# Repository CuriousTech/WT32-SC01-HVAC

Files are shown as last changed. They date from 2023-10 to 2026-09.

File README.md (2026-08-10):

# WT32-SC01-HVAC  

Thermostat vid  
  
WiFi Smart Omniscient Opensource Arduino ESP32 HVAC Touchscreen Thermostat using WT32-SC01 (not PLUS)  OSHPark [Rev1](https://oshpark.com/shared_projects/ljZTJh9A) $15.65  [Rev2](https://oshpark.com/shared_projects/giHlVB41)  

This code is currently too large for ESP-IDF 3.x.x but may be optimized further at some point. Another option is to replace the ESP32-WROVER-B module with the newer WROVER-E-N8R8 or N16R8, which increases the code space by 2x or even 4x.
  
This is the 3rd thermostat I've designed, only because new hardware makes it better, and tends to remove some limitations.  
All sensors from [ESP-HVAC](https://github.com/CuriousTech/ESP-HVAC), and older models can be used as remote units by building as REMOTE. This model can be changed to remote with just a temp/humidity sensor on the i2c pins, plus speaker if desired, and use the USB for power.  
  
This first version just emulated the Nextion HMI and kept all the code the same, except for Display.cpp/h, removal of any ESP8266 specific code, and the addition of an I/O pin to power the H/T sensor for reset purposes since it shares the i2c with the touch interface.  
Encoder.cpp/h was removed, but can be added back easily, with 4 extra I/O pins for expansion (IO36 is input only).  

The WT32-SC01 can be purchased from many vendors. It stays fairly cool, but the LM1117 is a bit inefficient, with a quiescent current of 5mA. These 2 linear regulators can be replaced with something better such as the AP2111H-3.3TRG1 to run it cooler. Soldering iron may be safer than a hot air gun unless the display is pulled away from the PCB (easy).  
  
To program: Copy the User_Setup/Setup201_WT32_SC01.h over the original. Some parameters were incorrect.  
Uncomment #include "Setup201_WT32_SC01.h" and comment the default in TFT_eSPI/User_Setup_Select.h  
Flash over USB first, and upload the SPIFFS data using ESP32 Sketch Data Uploader.  
If any libraries are missing, the error should be on the line with a link to the library. Some are in my ESP-HVAC repo.  
  
Some lines in code to change:  
&nbsp;&nbsp;&nbsp;&nbsp; Thermostat.ino: Uncomment the temp sensor used.  
&nbsp;&nbsp;&nbsp;&nbsp; HVAC.h: Uncomment #define REMOTE to compile for remote units. RMT1 should be changed to a uniique ID for each remote.  
&nbsp;&nbsp;&nbsp;&nbsp; WebHandler.cpp: ipFcServer(192,168,31,100); is the local forecast server IP. This is a comma delimited file for the current temps on a local server.  
&nbsp;&nbsp;&nbsp;&nbsp; eeMem.h: This has the SSID/password (or use EspTouch to set up), web access password, and OpenWeatherMap city ID, and many other default EEPROM values.  
&nbsp;&nbsp;&nbsp;&nbsp; OpenWeaetherMap.h: #define APPID "app id" is the long string from OpenWeatherMap.  
  
First test of the board came out almost perfect. The via close to the rectangle speaker can touch metal on the speaker and short. Use capton tape. It can go on the bottom or top. Bottom is better. The right capacitor doesn't clear the ESP32, even at 7mm tall. It only needs about 100uF at 25V, but more is better. They can be mounted to the back with the current case design.  
  
Thermal issues have been a struggle with this design, and the SHT40 is horrible sharing the i2c bus with the touchscreen. The AM2322 or AM2320 is a much better option. To reduce current, which effectively reduces heat, several changes were made: Setting clock to 80MHz instead of the default 240MHz, disabling the bluetooth radio, and lowering the LED backlight brightness (100 of 255) drops it from ~250mA to 150mA at 5V. Reducing the brightness further to 50 brings it down to ~80mA. At this point it produces very little heat, and is still almost bright enough for indoor visibility. 100 is really preferable.  
  
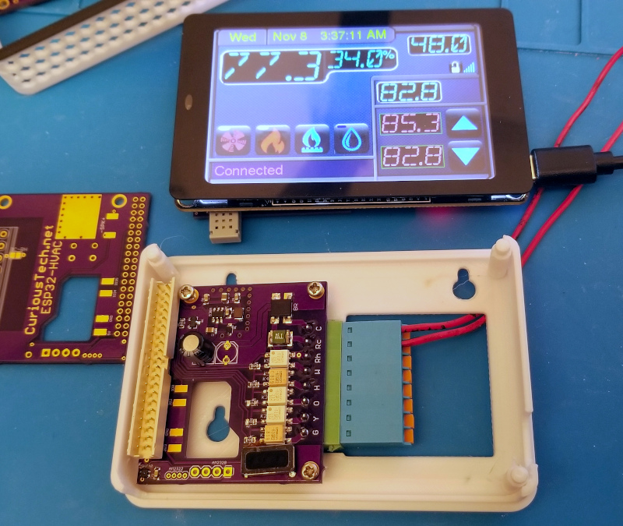
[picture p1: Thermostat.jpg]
Thermostat
  

With the printed case. I added about 5 inches of black before the white to match the display face (just stuck in front, not fused).  
  
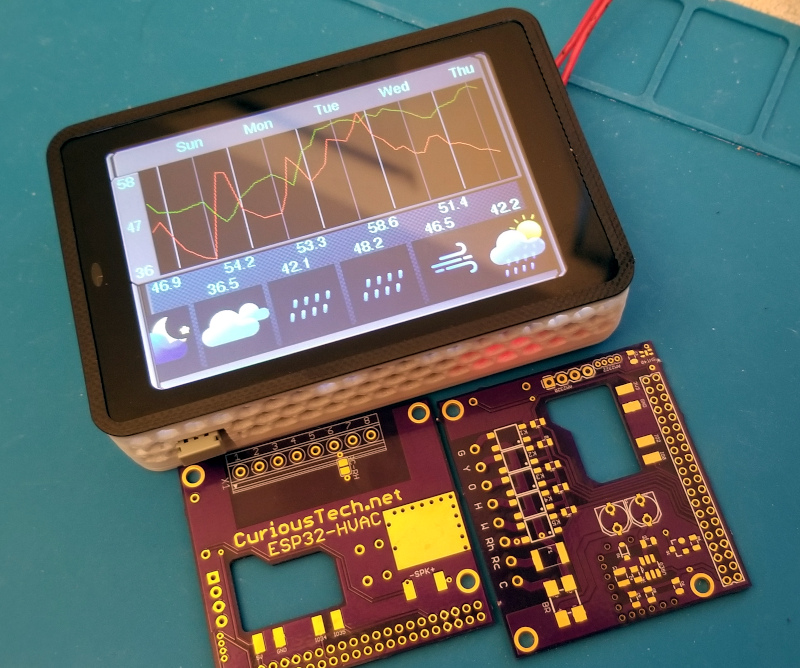
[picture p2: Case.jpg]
Case
  
  
HVAC wiring labels:  
 C (blue) common 24VAC  
 Rc (red or orange) 24VAC power for cool  (C and Rc power the thermostat)  
 Rh (red) 24VAC power for heat. Solder the Rc-Rh jumper on the back if not used.  
 Y (yellow) cool signal  
 O (color varies) compressor reverse for heatpump  
 W (white) heat signal  
 G (green) fan signal. Note: Heat and cool override manual fan signal.  
 H humidifier  
  
Main page:  

Cool/heat low/high:  
These are the desired temperature ranges for cooling and heating, which are calculated based on outside temperature over the next set number of days if using forecast.  

Cycle:  Disable heat and cool, but still cycles the fan by the Auto Fan: Run: settings. 4:00 and 5 default = 5 minutes every 4 hours.  

Threshold:  
The temperature offset to complete a cycle.  

Pre-cycle fan time:  
0 disables, 1 second to 5 minutes.  This is the first phase of the cycle.  When the temperature reaches the target, the fan is turned on to cycle air for the set time, which causes the thermostat to read a more overall temperature. If the threshold is reached before this ends, which it can, it will shut off. Otherwise it continues to the run phase, which runs for at least the cycleMin period to save wear on the compressor because this does shorten the run time considerably.  A good value to use is the time it takes to lower the temperature after turning the fan on before it plateaus.  Usually around 2 minutes. Note: The compressor and furnace have built-in timers as well, so make sure it's above them or it can get out of sync.  

Post-cycle fan time:  
Runs fan after cycle completes. This is the third phase of the cycle, which continues to push air through the cold radiator and ductwork. 2 minutes is good, but you can use an IR thermometer on a vent to see how long the cold air continues.  

Humidifier settings:  
Off: Always off  
Fan: Run when fan is on  
Run: Run when thermostat is running a cycle  
Auto1: Operate by humidistat during run cycles  
Auto2: Humidistat runs independently of thermostat (shares fan control)  

Override:  
Use to heat or cool by a selected offset temperature for a specified time.  

Freshen:  
Starts the fan with a timeout.  This uses the post fan timer, so a normal cycle will cancel it.  

Idle min, cycle min/max:  
These are timers in seconds to control the thermostat operating limits.  Idle min is the shortest time between cycles.  Cycle min is the shortest time for a cycle, and max is the longest.  The compressor has its own timers, so too short can get out of sync with the operation.  

Away time and temperature delta offset:  
The away time is in hours:minutes unlike the rest of the timers, but uses the override timer.  It can be turned on and off with the button, but will also turn off with the timer.  There are 2 temp values that are displayed depending on heat or cool mode.  One for heat and one for cool, like the pre/post fan.
Like any setting, it can be automated with something like Tasker.  To turn on would be <b>http://ip/s?key=password&away=1</b>  

Other settings:  
AC differential limit: Increases thermostat if inside/outside difference is more than 20. This assumes Fahrenheit. Change for Celsius.  
Heat Threshold: Heatpump will switch off and use gas when outside temp goes below set value (default 33). Change for Celsius.  
PKW (price per kilowatt hour), CFM (gas cubic feet per minute), CCF (cost per 100 cubic foot): Set the PPKW and CCF based on billing. CFM is dependent on the furnace.  
FC Shift (in minutes): Shifts the forecast for the temperature adjust. Use the setting on the chart page (they don't affect the actual settings) to determine what's best. There are 2 values for heat and cool here as well.   
Lookahead is for the forecast data. 23*3 hours default is a good range to find peaks in the current forecast. Disp is the amount to display on the unit.  
Brightness is the dim and bright backlight levels.  
Cal is calibration of the temp sensor.  
The arrows control the weight averaging of the internal temp sensor and remote sensors. Set them higher in rooms you're more often using or occupancy sensors can bump the weight.  
  
remotepage  

The web chart.  Dark gray is off, cyan is fan running, blue is compressor+fan, NG is red, HP is yellow, rh is green, the target/threshold is the wave.  The thermostat is in the hottest room in the house, so it does look warmer than it really is, but that's why there's a remote unit, and now multiple sensors.  
chartpage  

Sensor web page  
envmon

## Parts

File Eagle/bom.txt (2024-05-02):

PCB OSHPark $15.68 for 3

WT32-SC01
WT32-SC01 connector 98414-G06-40LF

X1          691305140008 (right angle)  or  TBP03R2-350-08BE (vertical) , 8 position 3.5mm pitch
            TBP03P2-350-08BEOR (plug with push connects) or 691361100008 (Screw terimal)

SPK         CMR-12062S-67 (12x6mm 32ohm square) Alternatiive: CDS-203-32-SP (round 20mm 32ohm speaker)

rh/temp sensor options:
 AM2320     (larger 4 pin, i2c)
 AM2322     (smaller 4 pin, i2c)

R1-R5       0805 200 (330 highest) // Edit: New rev of 61GR2 is 1.33V/5mA min (3.3V -> 1.33Vf = 200 for 10mA)
R6          0805 1K

K1-K5       G3VM-61GR2
F1          1812 PPTC Fuse 1.5A PTS181224V150
BR          MDB6S
VREG        LMR16006YQ5DDCRQ1
L1          0805 6.8uH IFSC0806AZER6R8M01
D1          SOT-223 NSVR0320MW2T1G
C1, C2      ESS107M025AE2AA (100uF / 25V / 6.3x7mm) (or 25SEPF56M 56uF 6.3x6mm)
C3-C7       0805 16V 0.1uF
C8          0805 16V 10uF
C9          0805 2.2uF

Q1          PMV20ENR

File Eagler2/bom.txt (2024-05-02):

PCB OSHPark $15.68 for 3

WT32-SC01
WT32-SC01 connector 98414-G06-40LF

X1          TBP03R2-350-08BE (vertical) and TBP03P2-350-08BEOR or
            39357-0008 (or 691322110008 and 691361100008) Screw terimal, 8 position 3.5mm pitch

SPK         CMR-12062S-67 (12x6mm 32ohm square) Alternatiive: CDS-203-32-SP (round 20mm 32ohm speaker)

rh/temp sensor options:
 AM2320     (larger 4 pin, i2c)
 AM2322     (smaller 4 pin, i2c)
 SHT40      (*requires advanced soldering skills)

R1-R5       0805 200 (330 highest) // Edit: New rev of 61GR2 is 1.33V/5mA min (3.3V -> 1.33Vf = 200 for 10mA)
R6          0805 1K

K1-K5       G3VM-61GR2
F1          1812 PPTC Fuse 1.5A PTS181224V150
BR          MDB6S
VREG        LMR16006YQ5DDCRQ1
L1          0805 6.8uH IFSC0806AZER6R8M01
D1          SOT-223 NSVR0320MW2T1G
C1, C2      ESS107M025AE2AA (100uF / 25V / 6.3x7mm) (or 25SEPF56M 56uF 6.3x6mm)
C3-C7       0805 16V 0.1uF
C8          0805 16V 10uF
C9          0805 2.2uF

Q1          PMV20ENR

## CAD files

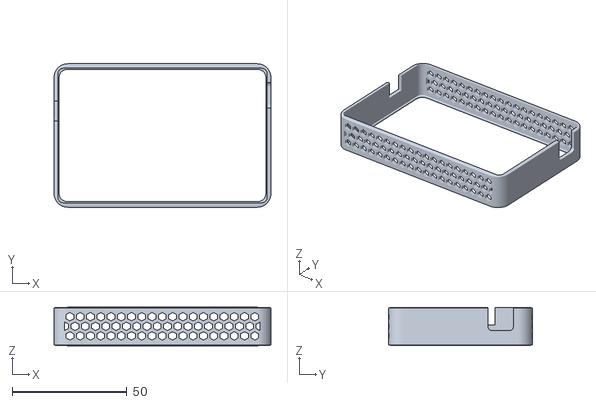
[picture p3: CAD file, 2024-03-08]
3D/R2RemoteFrontSideAM2322.stl
94.5 x 62.5 x 16.8

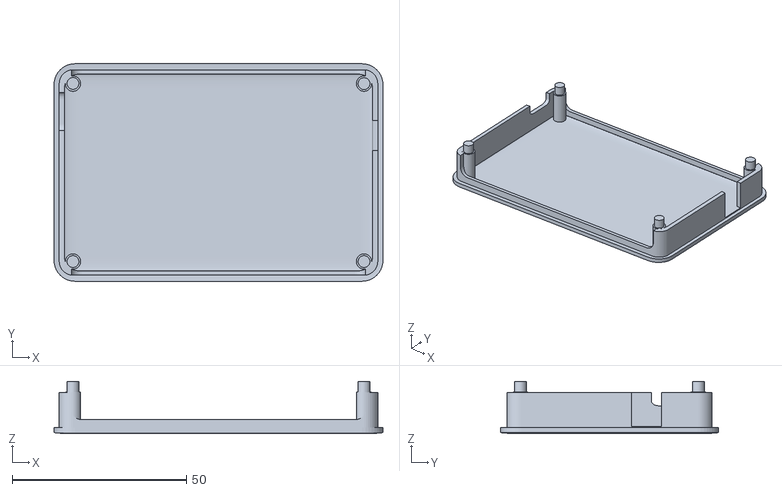
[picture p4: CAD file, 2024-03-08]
3D/R2RemoteBack.stl
94.5 x 62.5 x 15.0

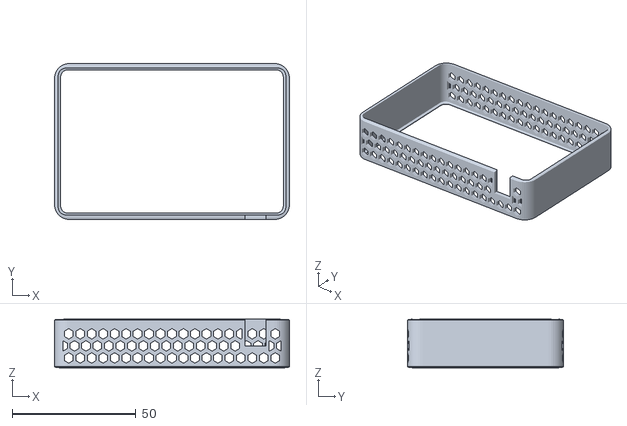
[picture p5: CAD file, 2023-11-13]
3D/FrontAM2322.stl
95.0 x 63.0 x 19.7

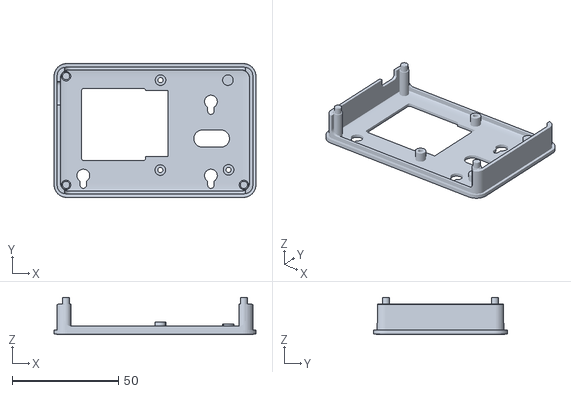
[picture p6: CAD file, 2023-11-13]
3D/Back.stl
95.0 x 63.0 x 17.5

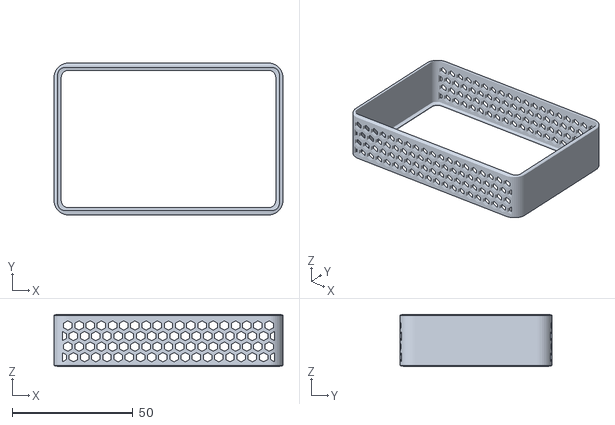
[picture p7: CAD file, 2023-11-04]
3D/FrontSHT40.stl
95.0 x 63.0 x 21.7

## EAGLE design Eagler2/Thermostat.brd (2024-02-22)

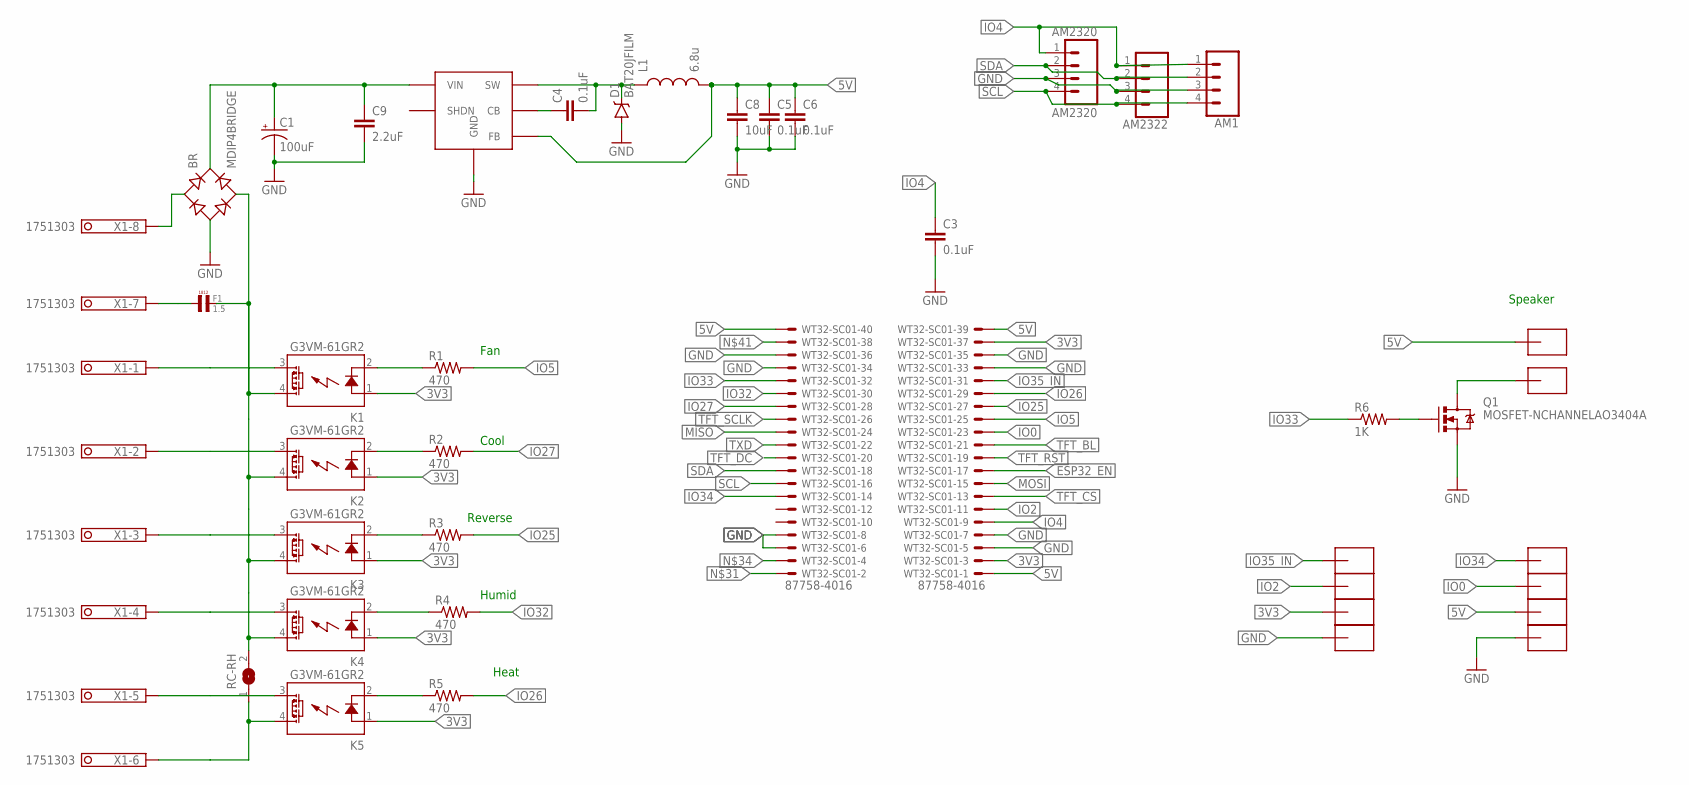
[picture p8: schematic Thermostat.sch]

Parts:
AM1, AM2322: CONN_041.27MM; 1X04_1.27MM
AM2320: AM2320; 1X04
BR: MDIP4BRIDGE; MICRODIP4
C1: 100uF; PANASONIC_C
C3, C4, C5, C6: 0.1uF; 0805
C8: 10uF; 0805
C9: 2.2uF; 0805
D1: BAT20JFILM; SOD-323
F1: 1.5; L4,8
K1, K2, K3, K4, K5: G3VM-61GR2; SOP04
L1: 6.8u; 1007
Q1: MOSFET-NCHANNELAO3404A; SOT23-3
R1, R2, R3, R4, R5: 470; 0805
R6: 1K; 0805
RC-RH: SJ
U$1, U$2, U$3, U$4, U$5, U$6, U$7, U$9, U$10, U$11: SMD-PAD1SMD-PAD80X32; SMD-PAD6
VREG: LMR16006YQ; SOT-23-6
WT32-SC01: 87758-4016
X1: 1751303

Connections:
3V3: K1.1 (A), K2.1 (A), K3.1 (A), K4.1 (A), K5.1 (A), U$1.>PAD, WT32-SC01.3, WT32-SC01.37
5V: C5.1, C6.1, C8.1, L1.2, U$5.>PAD, U$7.>PAD, VREG.3 (FB), WT32-SC01.1, WT32-SC01.39, WT32-SC01.40
ESP32_EN: WT32-SC01.17
GND: AM1.3, AM2320.3, AM2322.3, BR.-, C1.-, C3.2, C5.2, C6.2, C8.2, C9.2, D1.A, Q1.2 (S), U$2.>PAD, U$9.>PAD, VREG.2 (GND), WT32-SC01.5, WT32-SC01.6, WT32-SC01.7, WT32-SC01.8, WT32-SC01.33, WT32-SC01.34, WT32-SC01.35, WT32-SC01.36
IO0: U$10.>PAD, WT32-SC01.23
IO2: U$3.>PAD, WT32-SC01.11
IO4: AM1.1, AM2320.1, AM2322.1, C3.1, WT32-SC01.9
IO5: R1.2, WT32-SC01.25
IO25: R3.2, WT32-SC01.27
IO26: R5.2, WT32-SC01.29
IO27: R2.2, WT32-SC01.28
IO32: R4.2, WT32-SC01.30
IO33: R6.1, WT32-SC01.32
IO34: U$6.>PAD, WT32-SC01.14
IO35_IN: U$4.>PAD, WT32-SC01.31
MISO: WT32-SC01.24
MOSI: WT32-SC01.15
unnamed: C4.2, D1.C, L1.1, VREG.6 (SW)
unnamed: BR.AC2, F1.P$2 (2), K1.4 (DS1), K2.4 (DS1), K3.4 (DS1), K4.4 (DS1), RC-RH.2
unnamed: K4.2 (K), R4.1
unnamed: Q1.1 (G), R6.2
unnamed: K3.2 (K), R3.1
unnamed: K2.2 (K), R2.1
unnamed: K4.3 (DS2), X1.4
unnamed: K2.3 (DS2), X1.2
unnamed: K1.3 (DS2), X1.1
unnamed: K1.2 (K), R1.1
unnamed: C4.1, VREG.1 (CB)
unnamed: K5.3 (DS2), X1.5
unnamed: BR.AC1, X1.8
unnamed: K5.4 (DS1), RC-RH.1, X1.6
unnamed: F1.P$1 (1), X1.7
unnamed: BR.+, C1.+, C9.1, VREG.5 (VIN)
unnamed: K5.2 (K), R5.1
unnamed: K3.3 (DS2), X1.3
unnamed: Q1.3 (D), U$11.>PAD
SCL: AM1.4, AM2320.4, AM2322.4, WT32-SC01.16
SDA: AM1.2, AM2320.2, AM2322.2, WT32-SC01.18
TFT_BL: WT32-SC01.21
TFT_CS: WT32-SC01.13
TFT_DC: WT32-SC01.20
TFT_RST: WT32-SC01.19
TFT_SCLK: WT32-SC01.26
TXD: WT32-SC01.22

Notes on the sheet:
Speaker
Fan
Cool
Reverse
Humid
Heat

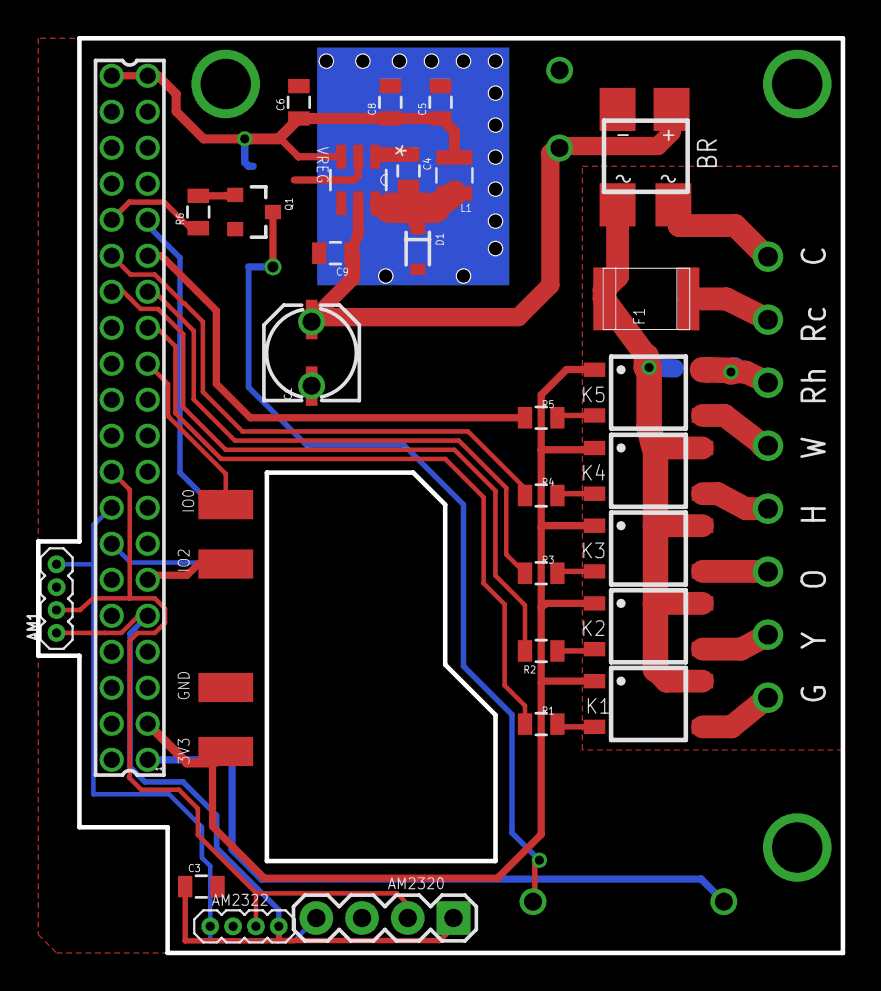
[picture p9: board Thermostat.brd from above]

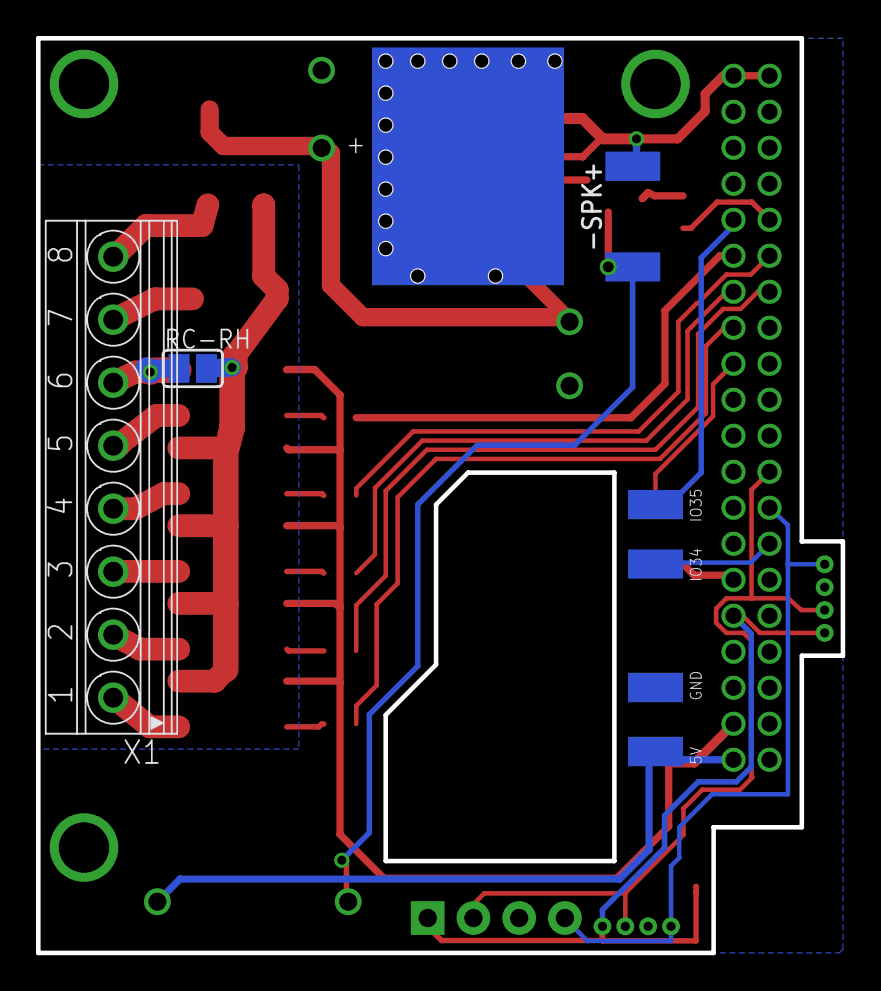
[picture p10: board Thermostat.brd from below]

Board: 2 copper layers, 44.7 x 50.8 mm, 40 parts (8 on the bottom side), 35 nets.

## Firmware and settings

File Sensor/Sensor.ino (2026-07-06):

/**The MIT License (MIT)

Copyright (c) 2016 by Greg Cunningham, CuriousTech

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
THE SOFTWARE IS PROVIDED "AS IS", WITHOUT WARRANTY OF ANY KIND, EXPRESS OR
IMPLIED, INCLUDING BUT NOT LIMITED TO THE WARRANTIES OF MERCHANTABILITY,
FITNESS FOR A PARTICULAR PURPOSE AND NONINFRINGEMENT. IN NO EVENT SHALL THE
AUTHORS OR COPYRIGHT HOLDERS BE LIABLE FOR ANY CLAIM, DAMAGES OR OTHER
LIABILITY, WHETHER IN AN ACTION OF CONTRACT, TORT OR OTHERWISE, ARISING FROM,
OUT OF OR IN CONNECTION WITH THE SOFTWARE OR THE USE OR OTHER DEALINGS IN THE
SOFTWARE.
*/

// Simple remote sensor for HVAC, with OLED display, AM2320 and PIR sensor or button
// This uses HTTP GET to send temp/rh

// Build with Arduino IDE 1.8.19, esp8266 SDK 3.1.2, 1MB (FS:64KB) (SPIFFS)

// Uncomment if using a direct OLED display
//#define USE_OLED

//uncomment to enable Arduino IDE Over The Air update code
#define OTA_ENABLE

#define IR_RX 5
#define IR_TX 14

#include <Wire.h>
#ifdef USE_OLED
#include <ssd1306_i2c.h> // https://github.com/CuriousTech/WiFi_Doorbell/tree/master/Libraries/ssd1306_i2c
#endif

#include <EEPROM.h>
#include <ESP8266mDNS.h>
#include <ESPAsyncWebServer.h> // https://github.com/me-no-dev/ESPAsyncWebServer
#include <TimeLib.h> // http://www.pjrc.com/teensy/td_libs_Time.html
#include "eeMem.h"
#include <JsonParse.h> // https://github.com/CuriousTech/ESP-HVAC/tree/master/Libraries/JsonParse
#include <JsonClient.h> // https://github.com/CuriousTech/ESP-HVAC/tree/master/Libraries/JsonClient
#include <FS.h>
#ifdef OTA_ENABLE
#include <ArduinoOTA.h>
#endif
#include "pages.h"
#include "jsonstring.h"
#include "uriString.h"
#include "TempArray.h"

// Uncomment only one
#include "tuya.h"  // Uncomment device in tuya.cpp
//#include "BasicSensor.h"

int serverPort = 80;

IPAddress lastIP;
IPAddress verifiedIP;
int nWrongPass;

uint32_t sleepTimer = 60; // seconds delay after startup to enter sleep (Note: even if no AP found)
int8_t nWsConnected;

AsyncWebServer server( serverPort );
AsyncWebSocket ws("/ws"); // access at ws://[esp ip]/ws
int WsClientID;

void jsonCallback(int16_t iName, int iValue, char *psValue);
JsonParse jsonParse(jsonCallback);
void jsonPushCallback(int16_t iName, int iValue, char *psValue, IPAddress ip);
JsonClient jsonPush(jsonPushCallback);

eeMem ee;

bool bPIRTrigger;
uint16_t displayTimer;
int32_t tzOffset;

#ifdef TUYA_H
TuyaInterface sensor;
#else
BasicInterface sensor;
#endif

#ifdef USE_OLED
SSD1306 display(0x3c, 5, 4); // Initialize the oled display for address 0x3c, sda=5, sdc=4
#endif

bool bConfigDone = false;
bool bStarted = false;
uint32_t connectTimer;
int16_t outTemp;
int16_t outRh;

TempArray temps;

String settingsJson()
{
  jsonString js("settings");

  js.Var("name", ee.szName);
  js.Var("to", ee.time_off );
  js.Var("srate", ee.sendRate);
  js.Var("lrate", ee.logRate);
  js.Var("sleep", ee.sleep);
  js.Var("o", ee.e.bEnableOLED);
  js.Var("l1", sensor.m_bLED[0]);
  js.Var("l2", sensor.m_bLED[1]);
  js.Var("pir", ee.e.bPIR);
  js.Var("pirpin", ee.pirPin);
  js.Var("prisec", ee.priSecs);
  js.Var("ch", ee.e.bCall);
  js.Var("cf", sensor.m_bCF);
  js.Var("df", sensor.m_dataFlags);
  js.Var("si", temps.m_bSilence);
  return js.Close();
}

String dataJson()
{
  jsonString js("state");

  js.Var("t", (uint32_t)now() - tzOffset - (DST() ? 3600:0) );
  js.Var("df", sensor.m_dataFlags);
  js.Var("temp", String( (float)sensor.m_values[DE_TEMP] / 10, 1 ) );
  js.Var("rh", String((float)sensor.m_values[DE_RH] / 10, 1) );
  js.Var("st", sleepTimer);
  int sig = WiFi.RSSI();
  sensor.setSignal(sig);
  js.Var("rssi", sig);

  if(sensor.m_dataFlags & DF_CO2 )
    js.Var("co2", sensor.m_values[DE_CO2] );
  if(sensor.m_dataFlags & DF_CH2O )
    js.Var("ch2o", sensor.m_values[ DE_CH2O ] );
  if(sensor.m_dataFlags & DF_VOC )
    js.Var("voc", sensor.m_values[ DE_VOC ] );
  
  return js.Close();
}

void displayStart()
{
  if(ee.e.bEnableOLED == false && displayTimer == 0)
  {
#ifdef USE_OLED
    display.init();
#endif
  }
  displayTimer = 30;
}

const char *jsonList1[] = {
  "key",
  "name",
  "reset",
  "tempOffset",
  "oled",
  "TZ",
  "TO",
  "srate",
  "lrate",
  "pir",
  "pri", // 10
  "prisec",
  "led1",
  "led2",
  "cf",
  "ch",
  "hostip",
  "hist",
  "ID",
  "sleep",
  "pirpin", // 20
  "alertidx",
  "alertlevel",
  "silence",
  "rhOffset",
  "wt",
  NULL
};

void parseParams(AsyncWebServerRequest *request)
{
  if(nWrongPass && request->client()->remoteIP() != lastIP)  // if different IP drop it down
    nWrongPass = 10;
  lastIP = request->client()->remoteIP();

  for ( uint8_t i = 0; i < request->params(); i++ )
  {
    const AsyncWebParameter* p = request->getParam(i);
    String s = request->urlDecode(p->value());

    uint8_t idx;
    for(idx = 0; jsonList1[idx]; idx++)
      if( p->name().equals(jsonList1[idx]) )
        break;
    if(jsonList1[idx])
    {
      int iValue = s.toInt();
      if(s == "true") iValue = 1;
      jsonCallback(idx, iValue, (char *)s.c_str());
    }
  }
}

bool bKeyGood;
bool bDataMode;

void jsonCallback(int16_t iName, int iValue, char *psValue)
{
  if(bKeyGood == false && iName != 0 && iName != 17 ) // allow hist
    return;  // only allow key set
  static int alertIdx;

  switch(iName)
  {
    case 0: // key
      if(!strcmp(psValue, ee.szControlPassword)) // first item must be key
      {
        bKeyGood = true;
        verifiedIP = lastIP;
      }
      break;
    case 1: // device name
      if(!strlen(psValue))
        break;
      strncpy(ee.szName, psValue, sizeof(ee.szName));
      ee.update();
      delay(1000);
      ESP.reset();
      break;
    case 2: // reset
      ee.update();
      delay(1000);
      ESP.reset();
      break;
    case 3: // tempOffset
      ee.tempCal = constrain(iValue, -80, 80);
      break;
    case 4: // OLED
      ee.e.bEnableOLED = iValue;
      break;
    case 5: // TZ
      break;
    case 6: // TO
      ee.time_off = iValue;
      break;
    case 7: // srate
      ee.sendRate = iValue;
      break;
    case 8: // lrate
      ee.logRate = iValue;
      break;
    case 9: // pir
      ee.e.bPIR = iValue;
      break;
    case 10: // pri
      break;
    case 11: // prisec
      ee.priSecs = iValue;
      break;
    case 12: // led1
      sensor.setLED(0, iValue ? true:false);
      break;
    case 13: // led2
      sensor.setLED(1, iValue ? true:false);
      break;
    case 14: // cf
      sensor.setCF(iValue ? true:false);
      break;
    case 15: // ch
      ee.e.bCall = iValue;
      break;
    case 16: // hostip
      ee.hostPort = 80;
      ee.hostIP[0] = lastIP[0];
      ee.hostIP[1] = lastIP[1];
      ee.hostIP[2] = lastIP[2];
      ee.hostIP[3] = lastIP[3];
      ee.e.bCall = 1;
      break;
    case 17: // hist
      temps.historyDump(true, ws, WsClientID);
      break;
    case 18:
      break;
    case 19:
      ee.sleep = iValue;
      break;
    case 20:
      ee.pirPin = iValue;
      break;
    case 21:
      alertIdx = constrain(iValue, 0, 15);
      break;
    case 22: // set alertidx first
      ee.wAlertLevel[alertIdx] = iValue;
      break;
    case 23:
      temps.m_bSilence = iValue ? true:false;
      break;
    case 24:
      ee.rhCal = iValue;
      break;
    case 25: // wt
      break;
  }
}

// Time in hh:mm[:ss][AM/PM]
String timeFmt(bool do_sec, bool do_M)
{
  String r = "";
  if(hourFormat12() < 10) r = " ";
  r += hourFormat12();
  r += ":";
  if(minute() < 10) r += "0";
  r += minute();
  if(do_sec)
  {
    r += ":";
    if(second() < 10) r += "0";
    r += second();
    r += " ";
  }
  if(do_M)
  {
      r += isPM() ? "PM":"AM";
  }
  return r;
}

const char *jsonListPush[] = {
  "tzoffset", // 0
  "time",
  "ppkw",
  "outtemp",
  "outrh",
  NULL
};

void jsonPushCallback(int16_t iName, int iValue, char *psValue, IPAddress ip)
{
  switch(iName)
  {
    case 0: // tzoffset
      tzOffset = iValue;
      break;
    case 1: // time
      setTime(iValue + tzOffset + (DST() ? 3600:0) );
      sensor.setDST( DST() );
      temps.m_bValidDate = true;
      break;
    case 3: // outtemp
      outTemp = iValue;
      break;
    case 4: // outrh
      outRh = iValue;
      break;
  }
}

void sendTemp()
{
  if(WiFi.status() != WL_CONNECTED || ee.hvacIP[0] == 0) // not set
    return;

  uriString uri("/s");
  uri.Param("key", ee.szControlPassword);
  uri.Param("rmtname", ee.szName);
  String s = String(sensor.m_values[DE_TEMP]);
  s += (ee.e.bCF) ? "F" : "C";
  uri.Param("rmttemp", s);
  uri.Param("rmtrh", sensor.m_values[DE_RH]);

  if(ee.e.bPIR && bPIRTrigger )
  {
    if(ee.priSecs)
      uri.Param("rmtto", ee.priSecs);
    bPIRTrigger = false;
  }

  IPAddress ip(ee.hvacIP);
  jsonPush.addQueue(ip, uri.string(), 80, "");
  jsonPush.setList(jsonListPush);
}

uint16_t stateTimer = 10;

void sendState()
{
  if(nWsConnected)
    ws.textAll(dataJson());
  stateTimer = ee.sendRate;
}

void findHVAC() // This seems to show only 6 at a time
{
  int n = MDNS.queryService("iot", "tcp");
  int d;
  for(int i = 0; i < n; ++i)
  {
    char szName[38];
    MDNS.hostname(i).toCharArray(szName, sizeof(szName));
    strtok(szName, "."); // remove .local

    if(!strcmp(szName, "HVAC"))
    {
      ee.hvacIP[0] = MDNS.IP(i)[0]; // update IP
      ee.hvacIP[1] = MDNS.IP(i)[1];
      ee.hvacIP[2] = MDNS.IP(i)[2];
      ee.hvacIP[3] = MDNS.IP(i)[3];
      break;
    }
  }
}

void onWsEvent(AsyncWebSocket * server, AsyncWebSocketClient * client, AwsEventType type, void * arg, uint8_t *data, size_t len)
{  //Handle WebSocket event
  static bool bRestarted = true;
  String s;

  switch(type)
  {
    case WS_EVT_CONNECT:      //client connected
      if(bRestarted)
      {
        bRestarted = false;
//        client->text("alert;Restarted");
      }
      client->keepAlivePeriod(50);
      client->text( settingsJson() );
      client->text( dataJson() );
      client->ping();
      nWsConnected++;
      break;
    case WS_EVT_DISCONNECT:    //client disconnected
      bDataMode = false; // turn off numeric display and frequent updates
      if(nWsConnected)
        nWsConnected--;
      break;
    case WS_EVT_ERROR:    //error was received from the other end
      break;
    case WS_EVT_PONG:    //pong message was received (in response to a ping request maybe)
      break;
    case WS_EVT_DATA:  //data packet
      AwsFrameInfo * info = (AwsFrameInfo*)arg;
      if(info->final && info->index == 0 && info->len == len){
        //the whole message is in a single frame and we got all of it's data
        if(info->opcode == WS_TEXT){
          data[len] = 0;

          uint32_t ip = client->remoteIP();
          WsClientID = client->id();

          bKeyGood = (ip && verifiedIP == ip) ? true:false; // if this IP sent a good key, no need for more
          jsonParse.process((char *)data);
          if(bKeyGood)
            verifiedIP = ip;
        }
      }
      break;
  }
}

void WsSend(String s)
{
  ws.textAll(s);
}

void alert(String txt)
{
  jsonString js("alert");
  js.Var("text", txt);
  ws.textAll(js.Close());
}

void setup()
{
  ee.init();
  sensor.init(ee.e.bCF);

  ee.time_off = 0;
  ee.pirPin = 0;
  // initialize dispaly
#ifdef USE_OLED
  display.init();
//  display.flipScreenVertically();
  display.clear();
  display.display();
#endif

  WiFi.hostname(ee.szName);
  WiFi.mode(WIFI_STA);

  if ( ee.szSSID[0] )
  {
    WiFi.begin(ee.szSSID, ee.szSSIDPassword);
    WiFi.setHostname(ee.szName);
    bConfigDone = true;
  }
  else
  {
    Serial.println("No SSID. Waiting for EspTouch.");
    WiFi.beginSmartConfig();
  }
  connectTimer = now();

  SPIFFS.begin();

  // attach AsyncWebSocket
  ws.onEvent(onWsEvent);
  server.addHandler(&ws);

  server.on( "/", HTTP_GET | HTTP_POST, [](AsyncWebServerRequest *request){
    parseParams(request);
    bDataMode = true;
//  request->send(SPIFFS, "/index.html");
    request->send_P(200, "text/html", page_index);
  });
  server.on( "/s", HTTP_GET | HTTP_POST, [](AsyncWebServerRequest *request){
    parseParams(request);

    String page = "{\"ip\": \"";
    page += WiFi.localIP().toString();
    page += ":";
    page += serverPort;
    page += "\"}";
    request->send( 200, "text/json", page );
  });
  server.on( "/json", HTTP_GET | HTTP_POST, [](AsyncWebServerRequest *request){
    parseParams(request);
    request->send( 200, "text/json", settingsJson() );
  });
  server.on("/heap", HTTP_GET, [](AsyncWebServerRequest *request){
    request->send(200, "text/plain", String(ESP.getFreeHeap()));
  });
  server.on("/favicon.ico", HTTP_GET, [](AsyncWebServerRequest *request){
    AsyncWebServerResponse *response = request->beginResponse_P(200, "image/x-icon", favicon, sizeof(favicon));
    response->addHeader("Content-Encoding", "gzip");
    request->send(response);
  });

  server.onNotFound([](AsyncWebServerRequest *request){
    request->send(404);
  });

  server.onFileUpload([](AsyncWebServerRequest *request, String filename, size_t index, uint8_t *data, size_t len, bool final){
  });
  server.onRequestBody([](AsyncWebServerRequest *request, uint8_t *data, size_t len, size_t index, size_t total){
  });

  server.begin();

#ifdef OTA_ENABLE
  ArduinoOTA.setHostname(ee.szName);
  ArduinoOTA.begin();
  ArduinoOTA.onStart([]() {
    ee.update();
    sensor.setLED(0, false); // set it all to off
    temps.saveData();
    SPIFFS.end();
    alert("OTA Update Started");
    ws.closeAll();
  });
#endif

  jsonParse.setList(jsonList1);
  sensor.setLED(0, false);
  if(ee.sendRate == 0) ee.sendRate = 60;
  sleepTimer = ee.sleep;
  temps.init(sensor.m_dataFlags);
  if(ee.pirPin)
    pinMode(ee.pirPin, INPUT);
}

void loop()
{
  static uint8_t hour_save, sec_save;
  static uint8_t cnt = 0;
  bool bNew;

  MDNS.update();
#ifdef OTA_ENABLE
  ArduinoOTA.handle();
#endif
  if(ee.pirPin)
  {
    static bool last_pir;
    if(digitalRead(ee.pirPin) != last_pir)
    {
      last_pir = digitalRead(ee.pirPin);
      if(last_pir)
      {
        if(ee.e.bPIR && bPIRTrigger)
          sendTemp();
        jsonString js("print");
        js.Var("text", "Motion");
        WsSend(js.Close());
      }
    }
  }

  static int htimer = 10;
  if(--htimer == 0)
  {
    temps.historyDump(false, ws, WsClientID);
    htimer = 30;
  }

  if(int err = sensor.service(ee.tempCal, ee.rhCal))
  {
  }

  jsonPush.service();

  if(sec_save != second()) // only do stuff once per second (loop is maybe 20-30 Hz)
  {
    sec_save = second();

    if(!bConfigDone)
    {
      if( WiFi.smartConfigDone())
      {
        Serial.println("SmartConfig set");
        bConfigDone = true;
        connectTimer = now();
      }
    }
    if(bConfigDone)
    {
      if(WiFi.status() == WL_CONNECTED)
      {
        if(!bStarted)
        {
          Serial.println("WiFi Connected");
          WiFi.mode(WIFI_STA);
          MDNS.begin( ee.szName );
          bStarted = true;
          MDNS.addService("iot", "tcp", serverPort);
          WiFi.SSID().toCharArray(ee.szSSID, sizeof(ee.szSSID)); // Get the SSID from SmartConfig or last used
          WiFi.psk().toCharArray(ee.szSSIDPassword, sizeof(ee.szSSIDPassword) );
          ee.update();

          findHVAC();
        }
      }
      else if(now() - connectTimer > 10 || WiFi.status() == WL_NO_SSID_AVAIL) // failed to connect for some reason
      {
        Serial.println("Connect failed. Starting SmartConfig");
        connectTimer = now();
        WiFi.mode(WIFI_AP_STA);
        WiFi.beginSmartConfig();
        bConfigDone = false;
        bStarted = false;
      }
    }

    if(hour_save != hour())
    {
      hour_save = hour();
      ee.update(); // update EEPROM if needed while we're at it (give user time to make many adjustments)
    }

    if(nWrongPass)
      nWrongPass--;

    if(displayTimer) // temp display on thing
      displayTimer--;

    if(sleepTimer && nWsConnected == 0 && WiFi.status() == WL_CONNECTED) // don't sleep until all ws connections are closed
    {
      if(--sleepTimer == 0)
      {
        if(ee.time_off)
        {
          uint32_t us = ee.time_off * 60022000;  // minutes to us calibrated
#ifdef USE_OLED
          display.displayOff();
#endif
          ESP.deepSleep(us, WAKE_RF_DEFAULT);
        }
      }
    }

    if(--stateTimer == 0 || sensor.m_bUpdated) // a 60 second keepAlive
    {
      if(sensor.m_bUpdated)
      {
        temps.update(sensor.m_values);
        sensor.m_bUpdated = false;
      }
      sendState();
    }

    static uint8_t sendTimer = 20;
    if(--sendTimer == 0)
    {
      sendTimer = ee.sendRate;
      sendTemp();
    }
    static uint8_t addTimer = 10;
    if(--addTimer == 0)
    {
      addTimer = ee.logRate;
      temps.add( (uint32_t)now() - tzOffset, ws, WsClientID);
    }
  }

  if(WiFi.status() != WL_CONNECTED)
  {
    delay(40);
    sensor.setLED(0, !sensor.m_bLED[0] );
    return;
  }/*
  else if(wifi.state() == ws_connecting)
  {
    sensor.setLED(0, true);
    delay(8);
    sensor.setLED(0, false);
    return;
  }*/

#ifdef USE_OLED
  static bool bClear;
  bool bDraw = (ee.e.bEnableOLED || displayTimer || bDataMode);
  if(bDraw == false && bClear)
    return;

  // draw the screen here
  display.clear();
  if(bDraw)
  {
    String s = timeFmt(true, true);
    s += "  ";
    s += dayShortStr(weekday());
    s += " ";
    s += String(day());
    s += " ";
    s += monthShortStr(month());
    s += "  ";

    Scroller(s);

    display.drawPropString(2, 47, String((float)temp/10, 1) + "]");
    display.drawPropString(64, 47, String((float)rh/10, 1) + "%");
    bClear = false;
  }
  else
    bClear = true;
  display.display();
#endif
}

bool DST() // 2016 starts 2AM Mar 13, ends Nov 6
{
  tmElements_t tm;
  breakTime(now(), tm);
  // save current time
  uint8_t m = tm.Month;
  int8_t d = tm.Day;
  int8_t dow = tm.Wday;

  tm.Month = 3; // set month = Mar
  tm.Day = 14; // day of month = 14
  breakTime(makeTime(tm), tm); // convert to get weekday

  uint8_t day_of_mar = (7 - tm.Wday) + 8; // DST = 2nd Sunday

  tm.Month = 11; // set month = Nov (0-11)
  tm.Day = 7; // day of month = 7 (1-30)
  breakTime(makeTime(tm), tm); // convert to get weekday

  uint8_t day_of_nov = (7 - tm.Wday) + 1;

  if ((m  >  3 && m < 11 ) ||
      (m ==  3 && d > day_of_mar) ||
      (m ==  3 && d == day_of_mar && hour() >= 2) ||  // DST starts 2nd Sunday of March;  2am
      (m == 11 && d <  day_of_nov) ||
      (m == 11 && d == day_of_nov && hour() < 2))   // DST ends 1st Sunday of November; 2am
    return true;
  return false;
}

// Text scroller optimized for very long lines
#ifdef USE_OLED
void Scroller(String s)
{
  static int16_t ind = 0;
  static char last = 0;
  static int16_t x = 0;

  if(last != s.charAt(0)) // reset if content changed
  {
    x = 0;
    ind = 0;
  }
  last = s.charAt(0);
  int len = s.length(); // get length before overlap added
  s += s.substring(0, 18); // add ~screen width overlap
  int w = display.propCharWidth(s.charAt(ind)); // first char for measure
  String sPart = s.substring(ind, ind + 18);
  display.drawPropString(x, 0, sPart );

  if( --x <= -(w))
  {
    x = 0;
    if(++ind >= len) // reset at last char
      ind = 0;
  }
}
#endif

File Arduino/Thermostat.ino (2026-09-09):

/**The MIT License (MIT)

Copyright (c) 2016 by Greg Cunningham, CuriousTech

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
THE SOFTWARE IS PROVIDED "AS IS", WITHOUT WARRANTY OF ANY KIND, EXPRESS OR
IMPLIED, INCLUDING BUT NOT LIMITED TO THE WARRANTIES OF MERCHANTABILITY,
FITNESS FOR A PARTICULAR PURPOSE AND NONINFRINGEMENT. IN NO EVENT SHALL THE
AUTHORS OR COPYRIGHT HOLDERS BE LIABLE FOR ANY CLAIM, DAMAGES OR OTHER
LIABILITY, WHETHER IN AN ACTION OF CONTRACT, TORT OR OTHERWISE, ARISING FROM,
OUT OF OR IN CONNECTION WITH THE SOFTWARE OR THE USE OR OTHER DEALINGS IN THE
SOFTWARE.
*/

// Build with Arduino IDE 1.8.57.0
//  ESP32: (2.0.17) ESP32 WRover Module, Default 4MB with spiffs (ESP32 partitions SPIFFS easiest)
//  In TFT_eSPI/User_Setup_Select.h use #include <User_Setups/Setup201_WT32_SC01.h>
//  In TJPeg_Decoder.cpp remove all Serial.println() calls, and in User_config.h remove #define TJPGD_LOAD_SD_LIBRARY
// For remote unit, uncomment #define REMOTE in HVAC.h

#include <ESPAsyncWebServer.h> // https://github.com/ESP32Async/ESPAsyncWebServer
#include <time.h>
#include "HVAC.h"
#include "WebHandler.h"
#include "display.h"
#include <Wire.h>
#include "eeMem.h"
#include "RunningMedian.h"
#include "Media.h"

#define TZ  "EST5EDT,M3.2.0,M11.1.0"  // https://github.com/nayarsystems/posix_tz_db/blob/master/zones.csv

// Uncomment only one of these
//#include <DHT.h>  // http://www.github.com/markruys/arduino-DHT
//#include <DallasTemperature.h> //DallasTemperature from library mamanger
#include <AM2320.h> // https://github.com/CuriousTech/ESP-HVAC/blob/master/Libraries/AM2320/AM2320.h

//----- Deffault i2c pins. Shared wiith touch. See HVAC.h for the rest -
#define SDA      18
#define SCL      19
#define AMPWR    4 // Used for resetting the sensor in case of failure
//------------------------

Display display;
eeMem ee;

HVAC hvac;
Media media;
tm gLTime;

RunningMedian<int16_t,25> tempMedian; //median of 25 samples

#ifdef dht_h
DHT dht;
#endif
#ifdef DallasTemperature_h
const int ds18Resolution = 12;
DeviceAddress ds18addr = { 0x28, 0xC1, 0x02, 0x64, 0x04, 0x00, 0x00, 0x35 };
unsigned int ds18delay;
unsigned long ds18lastreq = 1; //zero is special
const unsigned int ds18reqdelay = 5000; //request every 5 seconds
unsigned long ds18reqlastreq;
OneWire oneWire(2); //pin 2
DallasTemperature ds18(&oneWire);
#endif
#ifdef AM2303_H
AM2320 am;
#endif

extern void WsSend(String s);

void setup()
{
//  Serial.begin(115200);  // Just for debug (uses almost 10K)
//  Serial.println("starting");

  ee.init();
  pinMode(AMPWR, OUTPUT);
  digitalWrite(AMPWR, HIGH);
  display.init();
  hvac.init();
  startServer();

#ifdef dht_h
  dht.setup(UNSET, DHT::DHT22);
#endif
#ifdef DallasTemperature_h
  ds18.setResolution(ds18addr, ds18Resolution);
  ds18.setWaitForConversion(false); //this enables asyncronous calls
  ds18.requestTemperatures(); //fire off the first request
  ds18lastreq = millis();
  ds18delay = 750 / (1 << (12 - ds18Resolution)); //delay based on resolution
#endif
}

void loop()
{
  static uint8_t hour_save, min_save = 255, sec_save;
  static int8_t lastHour;
  static int8_t lastDay = -1;
  static uint32_t lastMS;

  display.service();  // check for touch, etc.
  handleServer(); // handles mDNS, web

#ifdef DallasTemperature_h
  if(ds18lastreq > 0 && millis() - ds18lastreq >= ds18delay) { //new temp is ready
    tempMedian.add((ee.b.bCelcius ? ds18.getTempC(ds18addr):ds18.getTempF(ds18addr)) );
    ds18lastreq = 0; //prevents this block from firing repeatedly
    float temp;
    if (tempMedian.getAverage(temp) == tempMedian.OK) {
      hvac.updateIndoorTemp( temp * 10, 500); //fake 50%
    }
  }

  if(millis() - ds18reqlastreq >= ds18reqdelay) {
    ds18.requestTemperatures(); 
    ds18lastreq = millis();
    ds18reqlastreq = ds18lastreq;
  }
#endif
    
  if(millis() - lastMS > 1000) // only do stuff once per second
  {
    lastMS = millis();

    getLocalTime(&gLTime);

    if(secondsServer()) // once per second stuff, returns true once on connect
    {
      configTzTime(TZ, "pool.ntp.org");

      if(lastDay == -1)
      {
        lastDay = gLTime.tm_mday - 1;
      }

    }
    display.oneSec();
    hvac.service();   // all HVAC code

#ifdef dht_h
    static uint8_t read_delay = 2;

    if(--read_delay == 0)
    {
      int16_t temp;
      if(ee.bCelcius)
        temp = dht.getTemperature() * 10;
      else
        temp = dht.toFahrenheit(dht.getTemperature()) * 10;

      if(dht.getStatus() == DHT::ERROR_NONE)
      {
        tempMedian.add(temp);
        if (tempMedian.getMedian(temp) == tempMedian.OK) {
          hvac.updateIndoorTemp( temp, dht.getHumidity() * 10);
        }
      }
      else
      {
        hvac.m_notif = Note_Sensor;
        display.updateNotification(true); // be annoying
      }

      read_delay = 5; // update every 5 seconds
    }
#endif

#ifdef AM2303_H
    static uint8_t read_delay = 2;
    static uint8_t errCnt = 0;

    if(--read_delay == 0)
    {
      int16_t temp;
      int16_t rh;
      if(digitalRead(AMPWR) == LOW)
      {
        digitalWrite(AMPWR, HIGH); // Power the AM2320
      }
      else if(am.measure(temp, rh))
      {
        int16_t t2 = temp;
        if(!ee.b.bCelcius)
          temp = temp * 9 / 5 + 320;
        tempMedian.add(temp);
        if (tempMedian.getMedian(temp) == tempMedian.OK) {
          hvac.updateIndoorTemp( temp, rh );
        }
        errCnt = 0;
      }
      else
      {
        digitalWrite(AMPWR, LOW); // Cut power to the AM2320
        if(errCnt < 5)
          errCnt++;
        else
        {
          hvac.m_notif = Note_Sensor;
          display.updateNotification(true); // be annoying
        }
      }
      read_delay = 5; // update every 5 seconds
    }
#endif

    if(min_save != gLTime.tm_min) // only do stuff once per minute
    {
      min_save = gLTime.tm_min;

      if(hour_save != gLTime.tm_hour) // update our IP and time daily (at 2AM for DST)
      {
        hour_save = gLTime.tm_hour;
        if(hour_save == 2)
        {
          configTzTime(TZ, "pool.ntp.org");
        }
#ifndef REMOTE
        if(hour_save == 0 && gLTime.tm_year > 124)
        {
          if(lastDay != -1)
          {
            hvac.dayTotals(lastDay);
            hvac.monthTotal(gLTime.tm_mon, gLTime.tm_mday);
          }
          lastDay = gLTime.tm_mday - 1;
          hvac.m_SecsDay[lastDay][0] = 0; // reset
          hvac.m_SecsDay[lastDay][1] = 0;
          hvac.m_SecsDay[lastDay][2] = 0;
          if(lastDay == 0) // new month
          {
            int m = (gLTime.tm_mon + 10) % 12; // last month: Dec = 10, Jan = 11, Feb = 0
            hvac.monthTotal(m, -1);
            memset(hvac.m_SecsDay, 0, sizeof(hvac.m_SecsDay)); // clear for new month
          }
        }

        ee.update();
        if((hour_save & 1) == 0) // every other hour
          hvac.saveStats();
#endif
      }
    }
  }
  delay(2);
}

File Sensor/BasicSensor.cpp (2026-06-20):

// Class for AM2320 temp and humidity

#include "BasicSensor.h"
#include <TimeLib.h> // http://www.pjrc.com/teensy/td_libs_Time.html

#define ESP_LED  2  // low turns on ESP blue LED
#define CF_BTN   13  // C/F button

extern void WsSend(String s);

void BasicInterface::init(bool bCF)
{
  pinMode(ESP_LED, OUTPUT);
  digitalWrite(ESP_LED, LOW);
  m_am.begin(5, 4);
  m_bCF = bCF;
}

int BasicInterface::service(int8_t tcal, int8_t rhcal)
{
  static uint8_t lastSec;

  if(second() == lastSec)
    return 0;

  lastSec = second();

  if((lastSec % 5) == 0)
  {
    int16_t temp;
    int16_t rh;

    if(m_am.measure(temp, rh))
    {
      m_status = 0;
      
      if(m_bCF)
        temp = temp * 9 / 5 + 320;
      temp += tcal;
      m_tempMedian[0].add( temp);
      m_tempMedian[0].getMedian(temp);
      m_tempMedian[1].add(rh);
      m_tempMedian[1].getMedian(rh);
      if(m_values[DE_TEMP] != temp || m_values[DE_RH] != rh)
        m_bUpdated = true;
      m_values[DE_TEMP] = temp;
      m_values[DE_RH] = rh + rhcal;
    }
    else
    {
      m_status = 1;
    }
  }

  static bool bBtn = true;
  if( digitalRead(CF_BTN) != bBtn )
  {
    bBtn = digitalRead(CF_BTN);
    if( bBtn ) // release
      setCF( !m_bCF );
  }
  return m_status;
}

void BasicInterface::setCF(bool f)
{
  m_bCF = f;
}

int BasicInterface::status()
{
  return m_status;
}

void BasicInterface::setDST(bool bDST)
{
  
}

void BasicInterface::setLED(uint8_t no, bool bOn)
{
  m_bLED[0] = bOn;
  digitalWrite(ESP_LED, !bOn);   // No external LED
}

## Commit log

2023-10-18 Update Thermostat.ino
    Sensor reset
    [Thermostat.ino]
2023-10-24 Added humidifier buttons
2023-10-24 Delete Arduino/pages.h
    Not used anymore
2023-10-24 Added a button
2023-10-24 Moved screensavers, added humidifier button
2023-11-04 Removed Wire.begin()
2023-11-04 Clearer connector options
2023-11-13 Possibly made some slight changes
    [Back.stl, FrontAM2322.stl]
2023-11-13 Shut down BT, changed to ESP32 Dev Module
2023-12-04 Switched to esp WebSocket client for stability
2024-01-20 Changed legend buttons
2024-01-20 Fixed dec place of outmin/max, furnace blower timer halved for 1/2 power
    [HVAC.cpp]
2024-02-09 New buttons for main screen
2024-02-09 forecast/history now called from buttons
2024-02-09 Untested heat/cool fail warnings, brightness settings
    [HVAC.cpp]
2024-02-22 Same as r0/r1 but optional side sensor for tabletop, 1st cap on back next to bridge rect.
2024-03-08 For rev2 board with side sensor (freestanding)
    [R2RemoteBack.stl, R2RemoteFrontSideAM2322.stl]
2024-05-02 Updated SSR resistors
2025-03-10 Override button added
2025-03-10 Cut down fonts
2025-04-13 Added history navigation buttons
2025-04-13 Fix not HP heating notif, add usage history files
    [HVAC.cpp]
2025-04-13 Add HP not heating notif
2025-04-29 Added restart button
2025-06-04 Fan state color update
2025-06-04 Current day lines removed on older months
2025-07-12 False sensor error on startup
    [HVAC.cpp]
2025-07-12 Current day/month number highlight
2025-07-19 Changed to esp32 time functions
2025-08-03 Using long names for sensors
2025-09-07 Switched to global time var
2026-03-30 Replaced digital font with drawing
    [Display.cpp]
2026-04-25 Update: Use ESP32 WRover Module
2026-04-25 Switched to sprite output
2026-04-26 Missed a refresh skip
    [Display.cpp]
2026-05-03 AM2320 integer value return
    Added AM2320 sensor library for temperature and humidity measurement.
2026-05-03 Refactor sensor measurement to use integers
2026-05-03 Refactor temperature handling to use int16_t
2026-06-14 Avoid forecast timer reset on damper calls
2026-06-20 Update Tuya interface with temperature and humidity handling
2026-07-03 Added 2 more sensors to the log
2026-07-03 Added sensors to log
2026-07-03 Swapped some bits to simplify the entries
    [Display.cpp]
2026-07-06 Added weight controls for sensors
2026-07-06 Simplified sensor weight control
2026-07-06 Added sensor weight
2026-07-06 Update README with sensor weight averaging details
    Clarified temperature sensor weight averaging and calibration instructions.
2026-09-09 Update comments for ESP32 configuration
2026-09-21 Fixed width sensor names
    Added a fixed-input class for better styling of input elements.

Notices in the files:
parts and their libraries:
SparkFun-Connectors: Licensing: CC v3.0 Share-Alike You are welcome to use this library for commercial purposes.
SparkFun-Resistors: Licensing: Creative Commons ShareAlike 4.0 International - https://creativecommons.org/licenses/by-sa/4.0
